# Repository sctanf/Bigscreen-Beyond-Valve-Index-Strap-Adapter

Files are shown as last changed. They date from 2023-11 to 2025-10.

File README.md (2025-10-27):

Repo for making an Index strap fit on a Beyond, ~~maybe~~ with working audio.

- Pi Pico DAC - https://github.com/sctanf/picoamp-2
- Recommended pogo pin is 9.5mm unloaded and 7.5mm loaded, 2.54mm pitch. Or refer to the diagram below. You can cut a 6pin version in half for each side. You can push out the middle pin from the springloaded side, if you prefer.

## Installation
1. Print a left and right side adapter in the original orientation with supports
- Non reversed version has the cable exiting towards the head, reversed version exits towards the front
- If it fits too loosely, you can put a few layers of electrical tape covering the Beyond's knob to add some resistance
- If you do not use the pogo pins and/or do not need Index audio, you can screw in the adapters now (step 3)
2. Feed 24-28ga wires through the adapter and solder the pogo pins
- Positive side is toward the head, negative side is toward the front
- Solder wires on the inside side of the pins so it fits inside the adapter
- For non reversed adapters, negative wire should extend a bit farther so it folds flat inside the adapter
- This can be done in any order but it may be a good idea to have pre-cut wire lengths and already wired to a plug or to picoamp
3. Press in the header and screw the adapters into the Index strap
- The tolerance should be very tight for a standard printer, if it does not fit try to trim the print a little bit
- You can reuse the screws from the Index or use equivalent screws
4. Connect to a DAC
- Again positive side is toward the head, negative side is toward the front, remember to check how the wires were folded in the adapter
- The intention is to use picoamp, but any sufficiently powerful DAC can be used, you ideally need around or at least 1W for ~6ohm impedance
- Usually a headphone DAC provides much less power than theoretical at these lower impedance, but something rated at least 200mW for 32ohms should work, ymmv
- For some common DACs or for software EQ (such as for Equalizer APO) there are a few presets and extra notes under [eq folder](../../tree/main/eq) and [picoamp](https://github.com/sctanf/picoamp-2) repository if needed

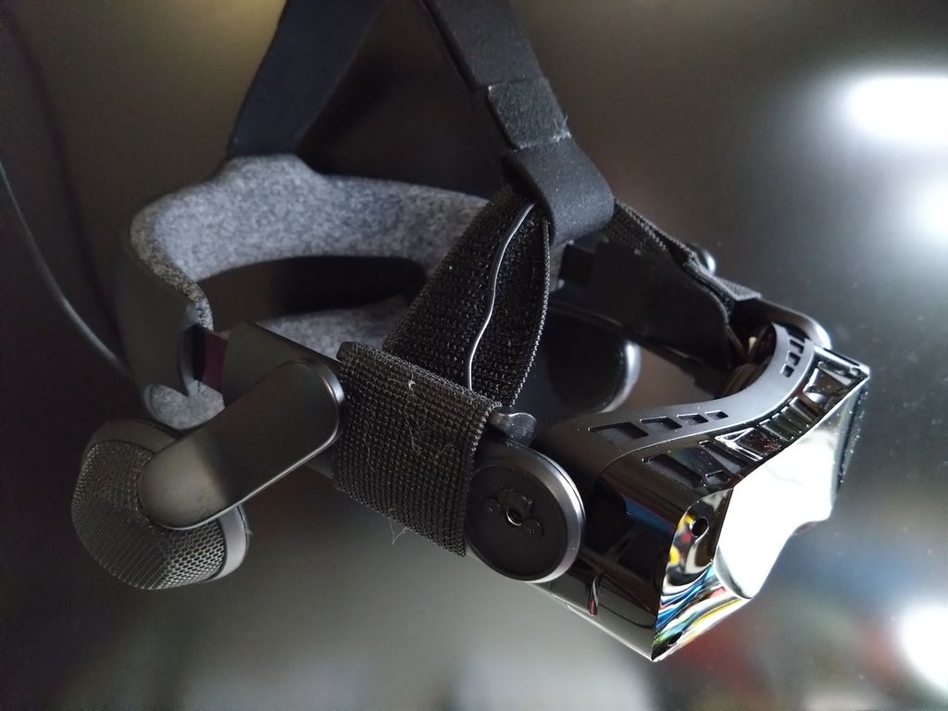
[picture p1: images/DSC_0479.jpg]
Beyond with an Index strap


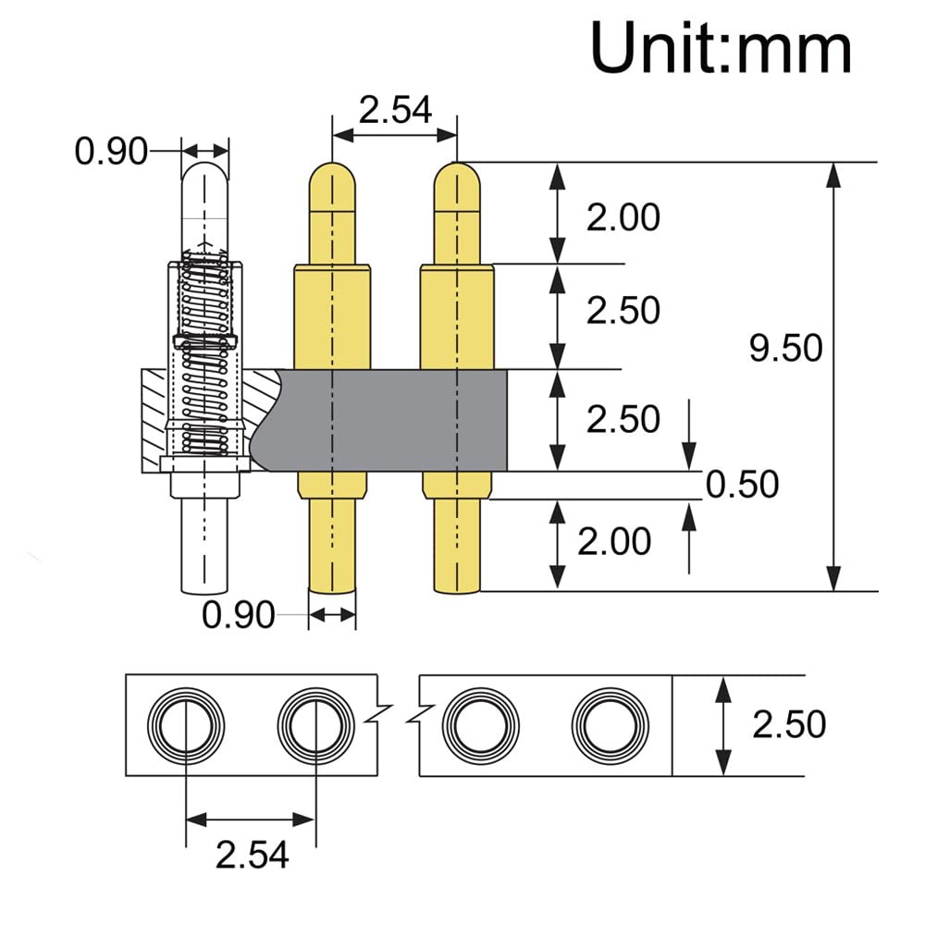
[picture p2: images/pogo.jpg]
pogo pins


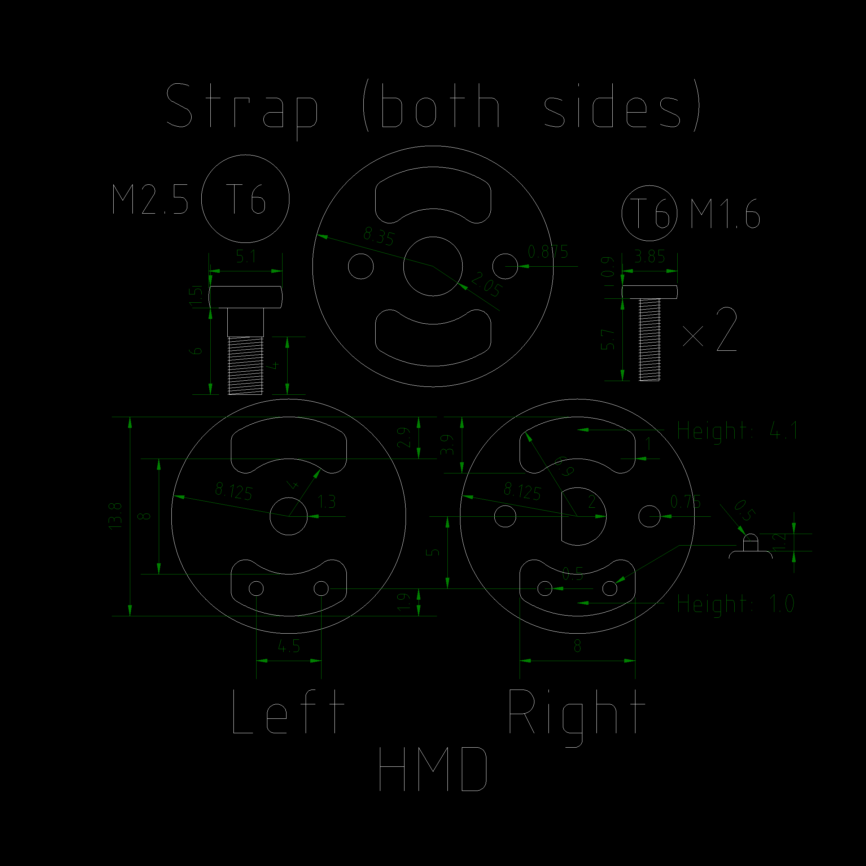
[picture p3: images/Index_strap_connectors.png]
Index mount drawings


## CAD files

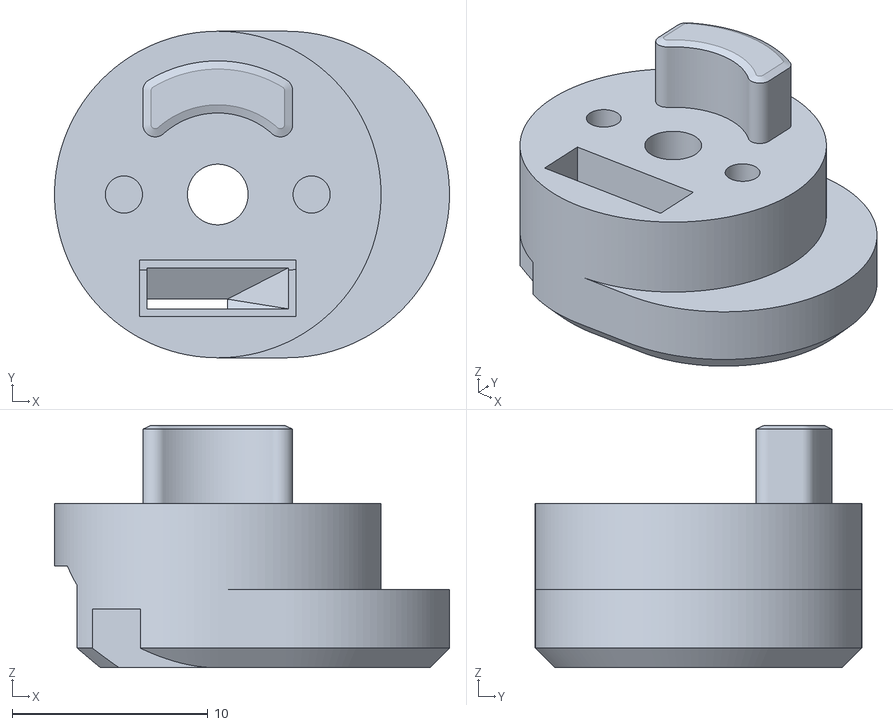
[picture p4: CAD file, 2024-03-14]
adapters v10/BBVIS Adapter v10, 0deg, R, No Hex.stl
20.2 x 16.7 x 12.4

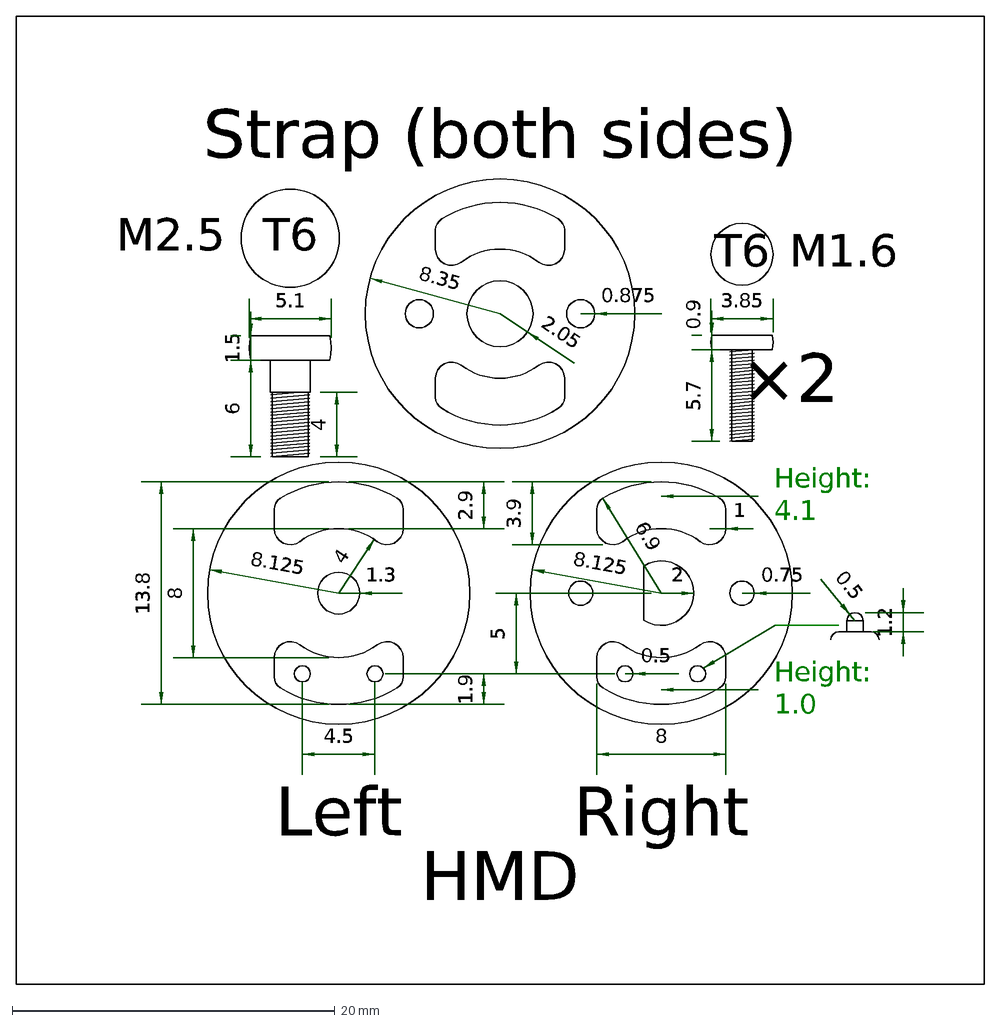
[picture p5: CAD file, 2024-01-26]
images/Index_strap_connectors.dxf
0.75
2
13.8
8
4.5
1.9
8.125
5
2.05
0.875
8.35
1.3
4
6.9
0.9
5.7
3.85
6
1.5
5.1
T6
M2.5
M1.6
×2
0.5
Left
HMD
Strap (both sides)
Right
1
Height: 4.1
Height: 1.0
1.2
3.9
2.9

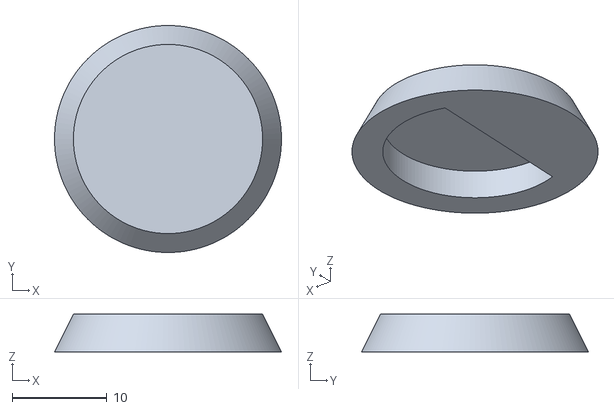
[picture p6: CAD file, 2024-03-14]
adapters v10/BBVIS Adapter v9, Knob Cover.stl
24.0 x 24.0 x 4.00

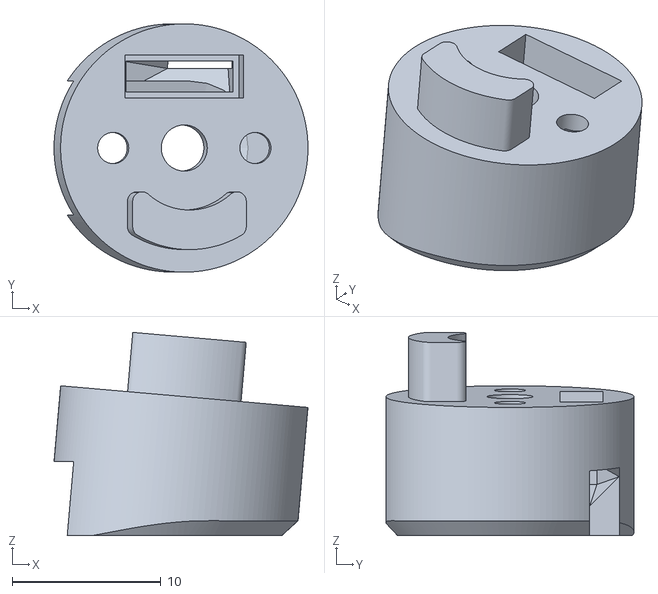
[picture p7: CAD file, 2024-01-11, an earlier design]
adapters v8/Beyond Index Strap Adapter - v8, Left, Hex Nut, Reverse Cable.stl
17.1 x 16.7 x 13.7

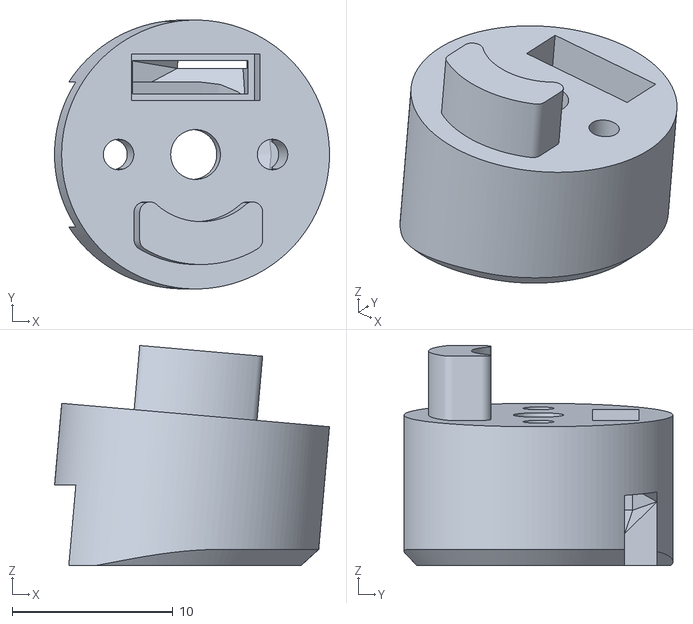
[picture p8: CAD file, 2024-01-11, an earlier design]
adapters v8/Beyond Index Strap Adapter - v8, Left, No Hex Nut, Reverse Cable.stl
17.1 x 16.7 x 13.7

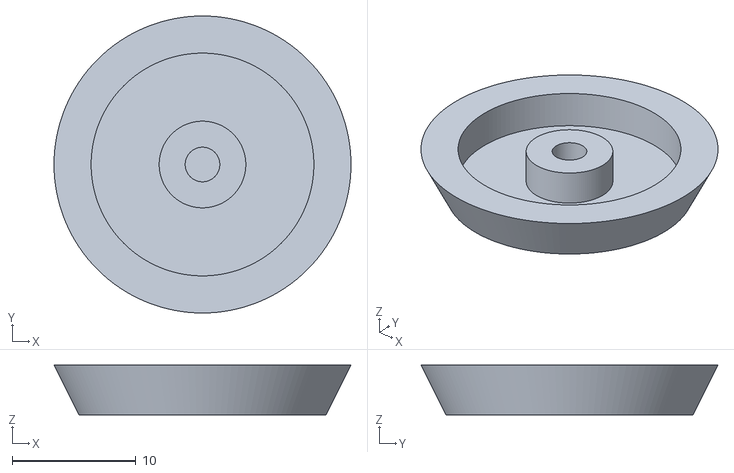
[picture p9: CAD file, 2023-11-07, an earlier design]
adapters v8/Beyond Index Strap Adapter Knob Cover - v8.stl
24.0 x 24.0 x 4.00

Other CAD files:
adapters v10/BBVIS Adapter v10, 0deg, L, No Hex.stl
adapters v8/Beyond Index Strap Adapter - v8, Right, Hex Nut, Reverse Cable.stl
adapters v8/Beyond Index Strap Adapter - v8, Right, No Hex Nut, Reverse Cable.stl
adapters v8/Beyond Index Strap Adapter - v8, Left, Hex Nut.stl
adapters v8/Beyond Index Strap Adapter - v8, Left, No Hex Nut.stl
adapters v8/Beyond Index Strap Adapter - v8, Right, No Hex Nut.stl
adapters v8/Beyond Index Strap Adapter - v8, Right, Hex Nut.stl

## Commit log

2024-01-11 Add left sided parts
    [Beyond Index Strap Adapter - v8, Left, Hex Nut, Reverse Cable.stl, Beyond Index Strap Adapter - v8, Left, Hex Nut.stl, Beyond Index Strap Adapter - v8, Left, N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]
2024-01-26 Add drawings by @zopiac
    [Index_strap_connectors.dxf]
2024-03-14 move old version and add new version
    v10 is tighter fitting and holds more flush against the headset to prevent wobbling
    [BBVIS Adapter v10, 0deg, L, No Hex.stl, BBVIS Adapter v10, 0deg, R, No Hex.stl, BBVIS Adapter v9, Knob Cover.stl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]
